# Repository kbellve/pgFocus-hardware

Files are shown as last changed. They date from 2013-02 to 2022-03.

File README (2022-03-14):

View this project on [CADLAB.io](https://cadlab.io/project/1071). 

pgFocus stands for Pretty Good Focus. It isn't "Definite" Focus nor "Perfect" Focus, but it is Pretty Good.  

pgFocus is fully compatible with uManager.

	1) Open Source Software

	2) Open Hardware

	3) Reasonably Fast
		pgFocus runs at 30Hz

	4) Reasonably inexpensive

	5) Independent of image capture
		In primary mode, pgFocus is asynchronous of uManager.

	6) uManager will be able to set, confirm or change focus positions through a uManager device adapter.

	7) Designed to work with a piezo Z controller for fastest response, but could be used to indirectly drive a motorized Z-Drive via a uManager device adapter.

	8) 3D Focus Stabilization
		Most focus stabilization devices turn off during 3D image capture, unlike pgFocus.

	9) Focus stability reporting
		You will quickly learn what disturbs your microscope and how to minimize those disturbances.

The pgFocus hardware, including all the files required to produce the hardware, is licensed under a Creative Commons Attribution-ShareAlike 4.0 International License.

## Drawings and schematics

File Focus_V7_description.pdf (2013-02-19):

## pgFocus by Karl Bellve Biomedical Imaging Group

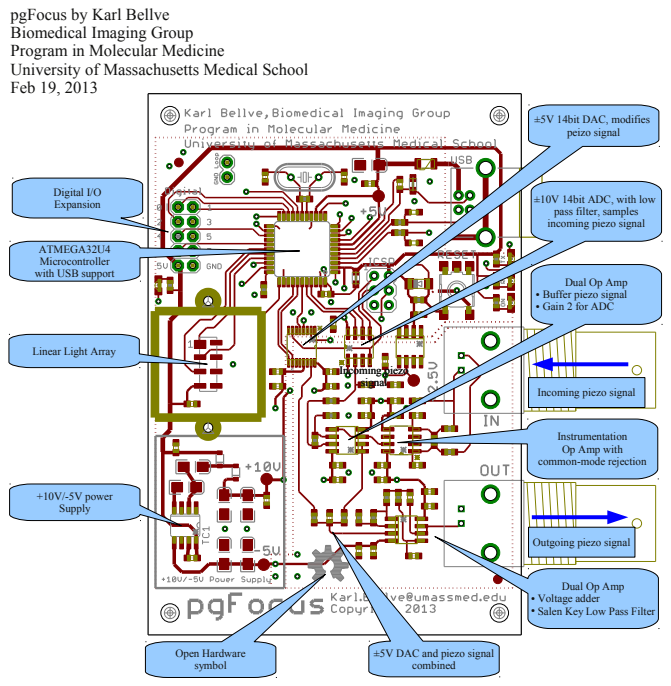
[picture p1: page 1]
+10V/-5V power Supply; ±5V 14bit DAC, modifies peizo signal; combined; Digital I/O Expansion; ATMEGA32U4 Microcontroller with USB support; Open Hardware symbol; Incoming piezo signal

Program in Molecular Medicine
University of Massachusetts Medical School
Feb 19, 2013

±10V 14bit ADC, with low
pass filter, samples
incoming piezo signal

Dual Op Amp
● Buffer piezo signal
● Gain 2 for ADC

Linear Light Array

Incoming piezo signal

Instrumentation
Op Amp with
common-mode rejection

Outgoing piezo signal

● Voltage adder
● Salen Key Low Pass Filter

±5V DAC and piezo signal

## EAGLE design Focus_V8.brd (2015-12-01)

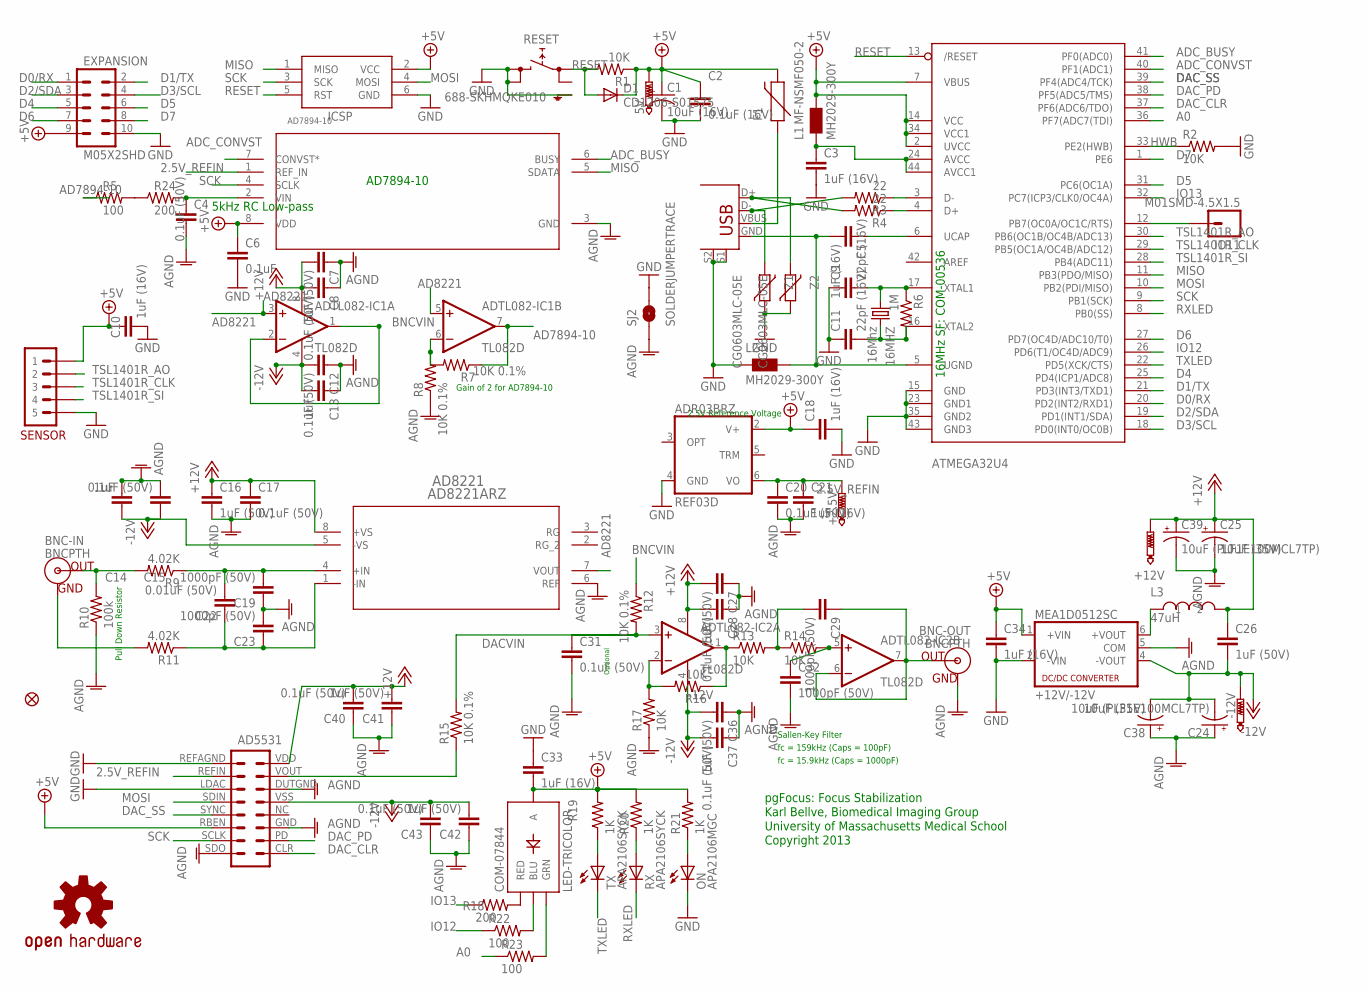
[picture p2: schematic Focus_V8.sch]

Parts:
5V: PTR1TP20R; TP20R
16MHZ: 16Mhz; HC49U-V
+2.5V, +12V: PTR1TP20R; TP20R
-12V: PTR1TP20R; TP20R
AD7894-10: AD7894ARZ-10; R_8
AD8221: AD8221ARZ; R_8
ADR03BRZ: REF03D; SO08
ADTL082-IC1, ADTL082-IC2: TL082D; SO08
ATMEGA32U4: ATMEGA32U4-AU; TQFP44
BNC-IN: BNCPTH; BNC
BNC-OUT: BNCPTH; BNC
C1: 10uF (16V); EIA3216-KIT
C2: 0.1uF (16V); 0603-CAP
C3, C5, C10, C18, C21, C33, C34: 1uF (16V); 0603-CAP
C4, C8, C12, C15, C17, C20, C28, C31, C37, C40, C43: 0.1uF (50V); 0603-CAP
C6: 0.1uF; 0603-CAP
C7, C16, C26, C27, C36, C41, C42: 1uF (50V); 0603-CAP
C9, C11: 22pF (16V); 0603-CAP
C13, C14: 1uF; 0603-CAP
C19, C23, C29, C32: 1000pF (50V); 0603-CAP
C22: 0.01uF (50V); 0603-CAP
C24, C39: 10uF (PLF1E100MCL7TP); CPOL-RADIAL-100UF-25V
C25, C38: 10uF (35V); EIA3216-KIT
COM-07844: LED-TRICOLOR; LED-TRICOLOR-SMD
D1: CD1206-S01575; MINIMELF
EXPANSION: M05X2SHD; 2X5-SHROUDED
F1: MF-NSMF050-2; PTC-1206
ICSP: AVRISP-6; AVRISP
IO11: M01SMD-4.5X1.5; PAD-1.5X4.5
JP1: FIDUCIAL1.5X3; FIDUCIAL-1.5X3
L1, L2: MH2029-300Y; 0805
L3: 47uH; 11R473C
MEA1D0512SC: +12V/-12V; NMA
ON: APA2106MGC; CHIPLED_0805
R1, R2, R13, R14, R16, R17: 10K; 0603-RES
R3, R4: 22; 0603-RES
R5, R22, R23: 100; 0603-RES
R6: 1M; 0603-RES
R7, R8, R12, R15: 10K 0.1%; 0603-RES
R9, R11: 4.02K; 0603-RES
R10: 100k; 0603-RES
R18, R24: 200; 0603-RES
R19, R20, R21: 1K; 0603-RES
RESET: 688-SKHMQKE010; SKHMPXE010
RX: APA2106SYCK; CHIPLED_0805
SENSOR: M05; M05JST-PTH
SJ2: SOLDERJUMPERTRACE; SJ_2S-TRACE
TX: APA2106SYCK; CHIPLED_0805
U$1: AD5531
U$3: OSHW-LOGOL; OSHW-LOGO-L
USB: USB+SHIELD; USB-B-PTH
Z1, Z2: CG0603MLC-05E; CT/CN0603

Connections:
2.5V_REFIN: +2.5V.TP, AD7894-10.1 (REF_IN), ADR03BRZ.6 (VO), C20.1, C21.1, U$1.REFIN
+5V: 5V.TP, AD7894-10.8 (VDD), ADR03BRZ.2 (V+), ATMEGA32U4.2 (UVCC), ATMEGA32U4.7 (VBUS), ATMEGA32U4.14 (VCC), ATMEGA32U4.34 (VCC1), C1.A (+), C2.1, C6.1, C10.1, C18.1, C33.2, C34.1, COM-07844.A, D1.C, EXPANSION.9, F1.2, ICSP.2 (VCC), L1.2, MEA1D0512SC.1 (+VIN), R1.1, R19.2, R20.2, R21.2, SENSOR.P$1 (1), U$1.RBEN
+12V: +12V.TP, AD8221.8 (+VS), ADTL082-IC1.8 (V+), ADTL082-IC2.8 (V+), C7.2, C8.2, C16.1, C17.1, C25.A (+), C26.1, C27.2, C28.2, C39.1 (+), C40.2, C41.2, L3.P$2 (2), U$1.VDD
-12V: -12V.TP, AD8221.5 (-VS), ADTL082-IC1.4 (V-), ADTL082-IC2.4 (V-), C12.2, C13.2, C14.1, C15.1, C24.2 (-), C26.2, C36.2, C37.2, C38.C (-), C42.2, C43.2, MEA1D0512SC.4 (-VOUT), U$1.VSS
A0: ATMEGA32U4.36 (PF7(ADC7(TDI)), R23.1
AD7894-10: ADTL082-IC1.7 (OUT), R5.1, R7.1
AD8221: AD8221.7 (VOUT), ADTL082-IC1.3 (+IN), ADTL082-IC1.5 (+IN)
ADC_BUSY: AD7894-10.6 (BUSY), ATMEGA32U4.41 (PF0(ADC0))
ADC_CONVST: AD7894-10.7 (CONVST*), ATMEGA32U4.40 (PF1(ADC1))
AGND: AD7894-10.3 (GND), AD8221.6 (REF), BNC-OUT.GND, C4.2, C7.1, C8.1, C12.1, C13.1, C14.2, C15.2, C16.2, C17.2, C19.1, C20.2, C21.2, C23.2, C24.1 (+), C25.C (-), C27.1, C28.1, C31.2, C32.2, C36.1, C37.1, C38.A (+), C39.2 (-), C40.1, C41.1, C42.1, C43.1, MEA1D0512SC.5 (COM), R8.1, R10.1, R17.1, SJ2.1, U$1.DUTGND, U$1.GND, U$1.SDO
BNCVIN: ADTL082-IC1.1 (OUT), ADTL082-IC1.2 (-IN), R12.1
D0/RX: ATMEGA32U4.20 (PD2(INT2/RXD1)), EXPANSION.1
D1/TX: ATMEGA32U4.21 (PD3(INT3/TXD1)), EXPANSION.2
D2/SDA: ATMEGA32U4.19 (PD1(INT1/SDA)), EXPANSION.3
D3/SCL: ATMEGA32U4.18 (PD0(INT0/OC0B)), EXPANSION.4
D4: ATMEGA32U4.25 (PD4(ICP1/ADC8)), EXPANSION.5
D5: ATMEGA32U4.31 (PC6(OC1A)), EXPANSION.6
D6: ATMEGA32U4.27 (PD7(OC4D/ADC10/T0)), EXPANSION.7
D7: ATMEGA32U4.1 (PE6), EXPANSION.8
DACVIN: ADTL082-IC2.3 (+IN), C31.1, R12.2, R15.2
DAC_CLR: ATMEGA32U4.37 (PF6(ADC6/TDO)), U$1.CLR
DAC_PD: ATMEGA32U4.38 (PF5(ADC5/TMS)), U$1.PD
DAC_SS: ATMEGA32U4.39 (PF4(ADC4/TCK)), U$1.SYNC
GND: ADR03BRZ.4 (GND), ATMEGA32U4.15 (GND), ATMEGA32U4.23 (GND1), ATMEGA32U4.35 (GND2), ATMEGA32U4.43 (GND3), C1.C (-), C2.2, C3.2, C6.2, C9.1, C10.2, C11.1, C18.2, C33.1, C34.2, EXPANSION.10, ICSP.6 (GND), L2.1, MEA1D0512SC.2 (-VIN), ON.CATHODE (C), R2.2, RESET.3 (2.1), RESET.4 (2.2), RESET.5 (SH), SENSOR.P$5 (5), SJ2.2, U$1.LDAC, U$1.REFAGND, USB.S1, USB.S2, Z1.1, Z2.1
HWB: ATMEGA32U4.33 (PE2(HWB)), R2.1
IO12: ATMEGA32U4.26 (PD6(T1/OC4D/ADC9)), R22.1
IO13: ATMEGA32U4.32 (PC7(ICP3/CLK0/OC4A)), R18.1
MISO: AD7894-10.5 (SDATA), ATMEGA32U4.11 (PB3(PDO/MISO)), ICSP.1 (MISO)
MOSI: ATMEGA32U4.10 (PB2(PDI/MISO)), ICSP.4 (MOSI), U$1.SDIN
unnamed: ADTL082-IC2.2 (-IN), R16.2, R17.2
unnamed: ADTL082-IC2.5 (+IN), C32.1, R14.2
unnamed: AD7894-10.2 (VIN), C4.1, R24.2
unnamed: AD8221.1 (-IN), C22.1, C23.1, R11.1
unnamed: R5.2, R24.1
unnamed: L3.P$1 (1), MEA1D0512SC.6 (+VOUT)
unnamed: ADTL082-IC2.1 (OUT), R13.1, R16.1
unnamed: R15.1, U$1.VOUT
unnamed: R19.1, TX.ANODE (A)
unnamed: ATMEGA32U4.4 (D+), R4.1
unnamed: 16MHZ.1, ATMEGA32U4.17 (XTAL1), C9.2, R6.1
unnamed: R20.1, RX.ANODE (A)
unnamed: BNC-IN.GND, R11.2
unnamed: AD8221.4 (+IN), C19.2, C22.2, R9.1
unnamed: ATMEGA32U4.6 (UCAP), C5.1
unnamed: C29.2, R13.2, R14.1
unnamed: BNC-IN.S (OUT), R9.2, R10.2
unnamed: ADTL082-IC1.6 (-IN), R7.2, R8.2
unnamed: R3.2, USB.D-, Z1.2
unnamed: ATMEGA32U4.3 (D-), R3.1
unnamed: R4.2, USB.D+, Z2.2
unnamed: F1.1, USB.VBUS
unnamed: ADTL082-IC2.6 (-IN), ADTL082-IC2.7 (OUT), BNC-OUT.S (OUT), C29.1
unnamed: ON.ANODE (A), R21.1
unnamed: ATMEGA32U4.24 (AVCC), ATMEGA32U4.44 (AVCC1), C3.1, L1.1
unnamed: 16MHZ.2, ATMEGA32U4.16 (XTAL2), C11.2, R6.2
unnamed: ATMEGA32U4.12 (PB7(OC0A/OC1C/RTS)), IO11.P$1
unnamed: COM-07844.R (RED), R18.2
unnamed: COM-07844.B (BLU), R22.2
unnamed: COM-07844.G (GRN), R23.2
RESET: ATMEGA32U4.13 (/RESET), D1.A, ICSP.5 (RST), R1.2, RESET.1 (1.1)
RXLED: ATMEGA32U4.8 (PB0(SS)), RX.CATHODE (C)
SCK: AD7894-10.4 (SCLK), ATMEGA32U4.9 (PB1(SCK)), ICSP.3 (SCK), U$1.SCLK
TSL1401R_AO: ATMEGA32U4.30 (PB6(OC1B/OC4B/ADC13)), SENSOR.P$2 (2)
TSL1401R_CLK: ATMEGA32U4.29 (PB5(OC1A/OC4B/ADC12)), SENSOR.P$3 (3)
TSL1401R_SI: ATMEGA32U4.28 (PB4(ADC11)), SENSOR.P$4 (4)
TXLED: ATMEGA32U4.22 (PD5(XCK/CTS)), TX.CATHODE (C)
UGND: ATMEGA32U4.5 (UGND), C5.2, L2.2, USB.GND

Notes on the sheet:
Pull Down Resistor
pgFocus: Focus Stabilization
2.5V Reference Voltage
16MHz SF: COM-00536
Sallen-Key Filter
fc = 159kHz (Caps = 100pF)
fc = 15.9kHz (Caps = 1000pF)
Karl Bellve, Biomedical Imaging Group
University of Massachusetts Medical School
Copyright 2013
AD7894-10
5kHz RC Low-pass
Gain of 2 for AD7894-10
Optional

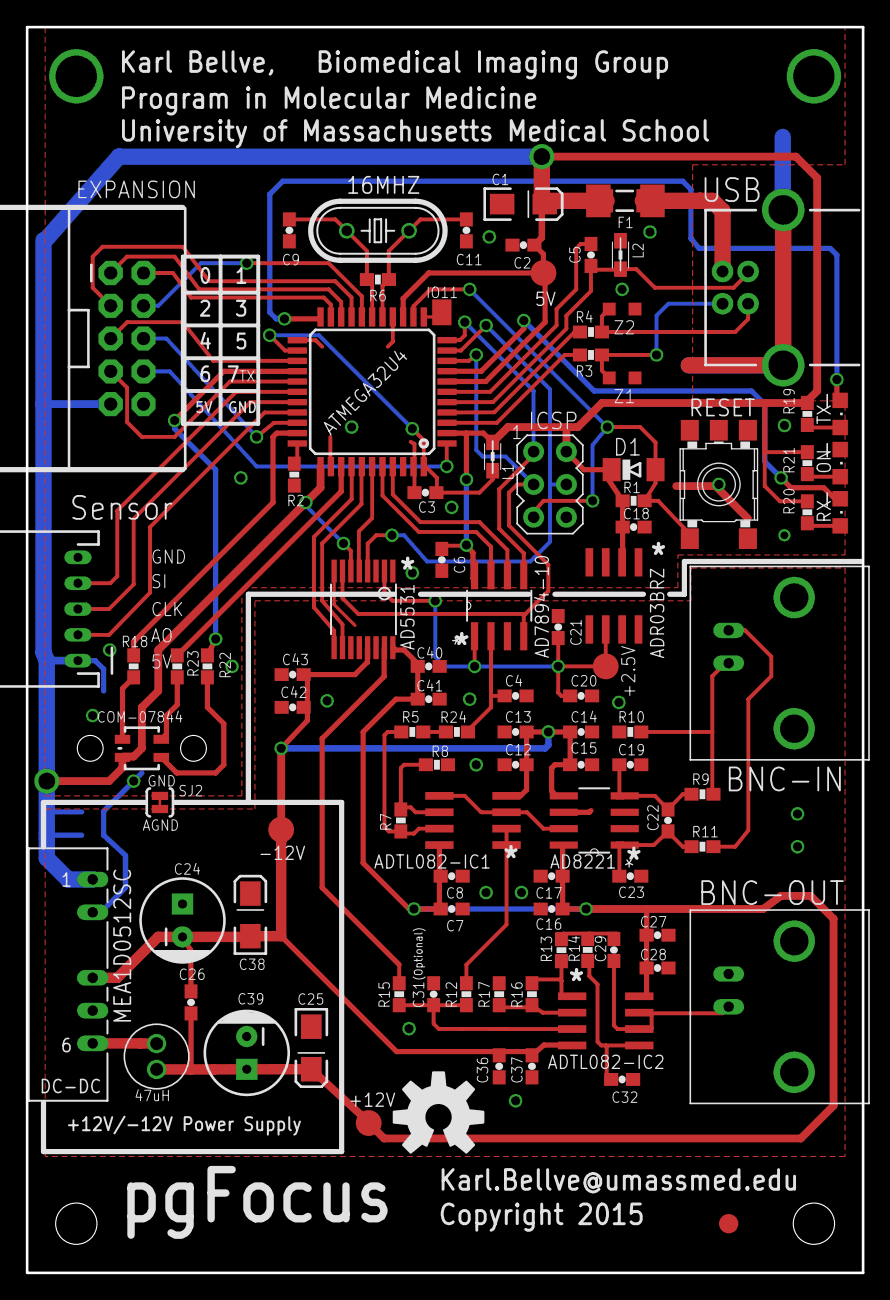
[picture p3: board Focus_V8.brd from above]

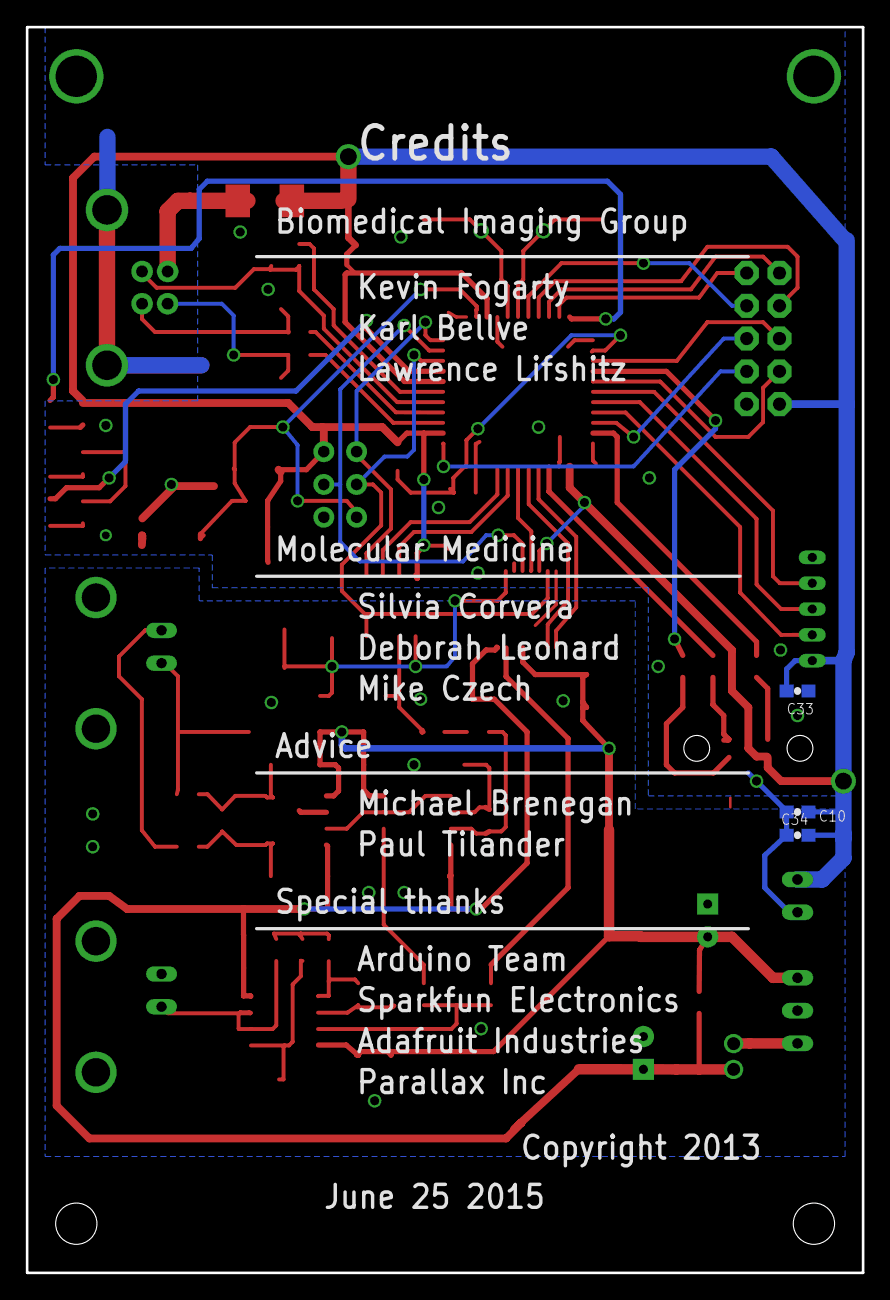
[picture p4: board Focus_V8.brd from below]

Board: 2 copper layers, 64.8 x 96.5 mm, 101 parts (3 on the bottom side), 67 nets.

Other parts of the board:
U$2: SMD-22

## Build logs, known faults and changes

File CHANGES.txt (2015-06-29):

June 29 2015

I will be posting to github a new main circuit board for pgFocus with a few small changes. This new version has not been tested yet.

I have removed  the LCD connector. In the past, I found that the driving a LCD would introduce too much noise into pgFocus, so I have never used it.

I have moved the RGB LED to the back edge of the circuit board. This reduces the bending strain on the optical light pipe. 

The RGB LED does introduce noise into the pgFocus analog circuit, but I only change the RGB LED when pgFocus loses focus control, or gains focus control, not during focus control.

I have also moved both the sensor and expansion connectors. They are both closer to the edge of the back of the board. They should now protrude through the back plate. This simplifies the containing packaging of pgFocus.

I also moved the large rear +5V circuit to the bottom layer of the board, and not the top layer. 

New date on the back of June 25, 2015.

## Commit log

2013-02-19 Added eagle schematic and board files
    [Focus_V7.brd, Focus_V7.sch]
2013-02-19 Description of board layout
2013-02-20 Adding PDF of top and bottom of board
2013-02-20 Top and Bottom of board
2013-02-22 Changed hole size from 1.6 to 2.2mm for TSL1401CL shroud
    [Focus_V7.brd, Focus_V7.sch]
2013-02-27 Pin 7 of TC7660 has a capacitor labeled C35, which should have been connected to ground, and not 5V This has been corrected in this revision. C35 is optional, and not needed. Only use if trying to sl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
    [Focus_V7.brd, Focus_V7.sch]
2013-03-11 LDAC pin of AD5531 needs to be tied to ground, Clean up of text
    [Focus_V7.brd, Focus_V7.sch]
2013-04-05 Version 8 removes the Linear Light Array and uses a TSL1401CL-Adapter Board via a 5 pin JST SH connector. There is also a 3 pin JST connector for communicating with a Serial Enabled LCD display RGB L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
    [Focus_V8.brd, Focus_V8.sch]
2013-04-05 Minor changes
    [Focus_V8.brd, Focus_V8.sch]
2013-04-11 Changed connector for Expansion, cleaned up text
    [Focus_V8.brd, Focus_V8.sch]
2013-04-24 Switchedd top two holes 1/8" Vias for mounting for chasis grounding
    [Focus_V8.brd, Focus_V8.sch]
2013-05-01 Latest version sent to manufacturing
    [Focus_V8.brd, Focus_V8.sch]
2013-09-20 Change connection between analog and digital ground plans via a cutable trace, which means that both ground planes will be connected by default.
    Also pin 6 (RBEN) of AD5531 was mistakenly left floating, now connected to 5V line to
    force deactivation.
    [Focus_V8.brd, Focus_V8.sch]
2013-10-16 Removed V7 pgFocus
    [Focus_V7.brd, Focus_V7.sch]
2015-06-29 Small changes to connectors on the rear edge of the main board. Reposition the sensor and expansion connector Removed the LCD connector Repositioned the RGB LED
2015-12-01 Updating to eliminate serial LCD connector, and to make a horizontal expansion possible. This simplifies using a box to contain the PCB
    [Focus_V8.brd, Focus_V8.sch]

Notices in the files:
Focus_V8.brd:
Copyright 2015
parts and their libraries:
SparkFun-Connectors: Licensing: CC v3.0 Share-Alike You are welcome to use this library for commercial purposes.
